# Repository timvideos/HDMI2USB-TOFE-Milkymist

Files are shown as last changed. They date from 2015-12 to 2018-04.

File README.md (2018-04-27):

## Milkymist Compatibility - TOFE Expansion board

The [Numato Opsis board](https://numato.com/product/numato-opsis-fpga-based-open-video-platform) is
already very similar to the [Milkymist M1](http://m-labs.hk/m1.html) and
[Mixxeo](http://m-labs.hk/mixxeo.html) devices created by
[M-Labs](http://m-labs.hk/), but lacks the DJ hardware interfaces. This
expansion board adds these missing components.

This board can be ordered from the
[Numato Opsis page on CrowdSupply.com](https://www.crowdsupply.com/numato-lab/opsis).

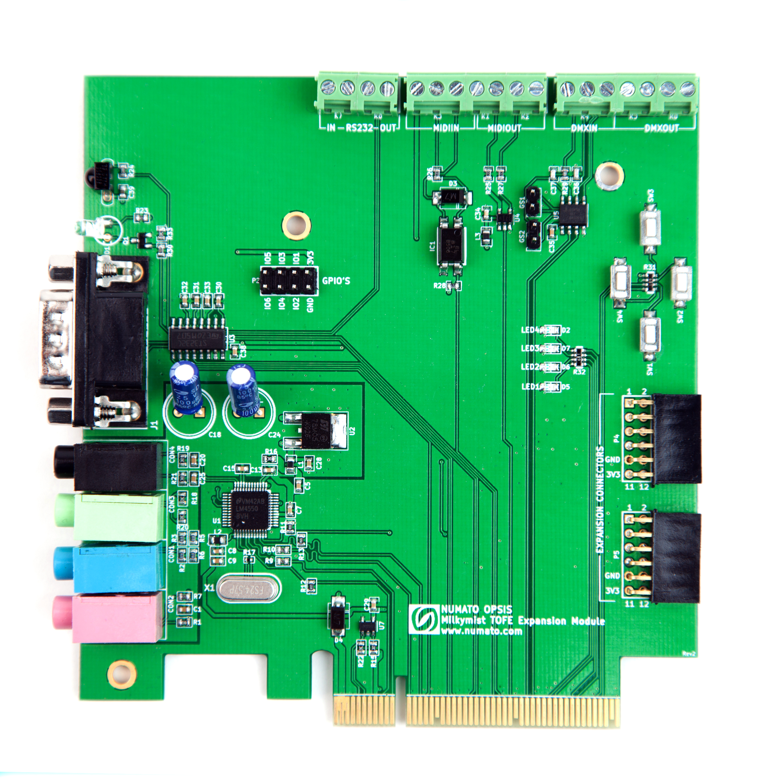
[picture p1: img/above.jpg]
Board Image


## Features

This extension board has the following features;

 * [AC‘97 compatible](https://en.wikipedia.org/wiki/AC%2797)
   audio interface with Microphone, Headphones, Line In + Out (on standard
   3.5mm connectors).

 * [RS-422](https://en.wikipedia.org/wiki/RS-422) / [RS-485](https://en.wikipedia.org/wiki/RS-485)
   compatible high speed (10Mbps), full duplex serial port;

    * Compatible with wide range of interfaces including the industry standard
      [DMX512 control protocol](https://en.wikipedia.org/wiki/DMX512).

    * Connected to screw terminal headers, allowing wiring to DB-9, RJ-12,
      XLR-5, XLR-3 or RJ-45 connectors (wiring diagrams provided).

 * [RS-232](https://en.wikipedia.org/wiki/RS-232) full duplex serial port on a
   standard DB-9 connector. Supporting connection to wide range of devices with
   serial ports. (A secondary RS-232 full duplex serial port on a standard
   screw terminal.)

 * [MIDI](https://en.wikipedia.org/wiki/MIDI) In and Out interfaces on screw
   terminals, supporting connection to wide range of musical instruments and
   control devices.

 * [Infrared](https://learn.adafruit.com/ir-sensor/ir-remote-signals)
   transmitter and receiver compatible with manys
   [consumer remote protocols](https://en.wikipedia.org/wiki/Consumer_IR).

 * 4 x Push button Switches,
 * 4 x Indicator LEDs,

 * 2 x [Digilent Pmod™ Compatible](http://www.digilentinc.com/Pmods/licensing.cfm)
   headers to allow usage of existing expansion boards, including boards froms
   [Numato Lab](http://numato.com/fpga-boards/filter/cat/expansion-modules.html?limit=30),
   [Digilent](http://digilentinc.com/pmods),
   [Maxim](https://www.maximintegrated.com/en/design/design-technology/fpga-design-resources/pmod-compatible-plug-in-peripheral-modules.html) ands
   [Analog](https://wiki.analog.com/resources/alliances/xilinx#pmods).

A PDF version of the schematic can be found in the [docs](docs) directory.

## Editing

The design in this repository was made using [KiCad](http://www.kicad-pcb.org/)
version **2013-07-07 BZR 4022**
([the version is Ubuntu Trusty](http://packages.ubuntu.com/trusty/kicad)).

## License

TOFE MilkyMist Compatibility Expansion board by Numato Systems Pvt. Ltd

TOFE MilkyMist Compatibility Expansion board is licensed under a
Creative Commons Attribution-ShareAlike 4.0 International License.

You should have received a copy of the license along with this
work. If not, see <http://creativecommons.org/licenses/by-sa/4.0/>.



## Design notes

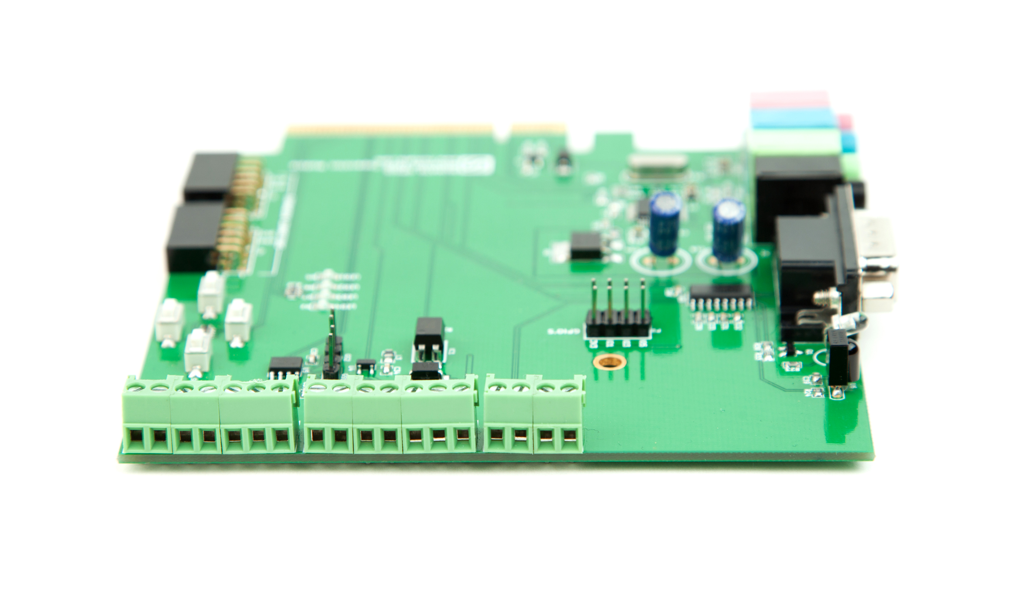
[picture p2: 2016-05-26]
img/top-edge.jpg

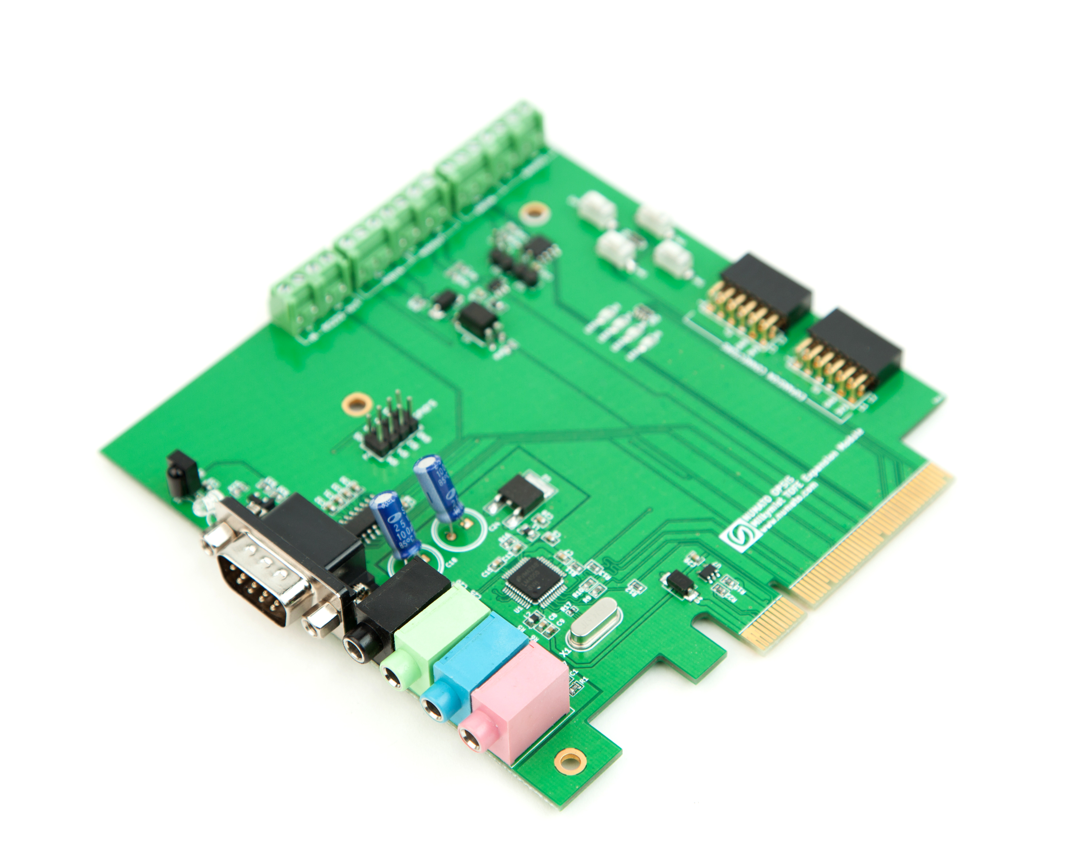
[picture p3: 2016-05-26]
img/45degree.jpg

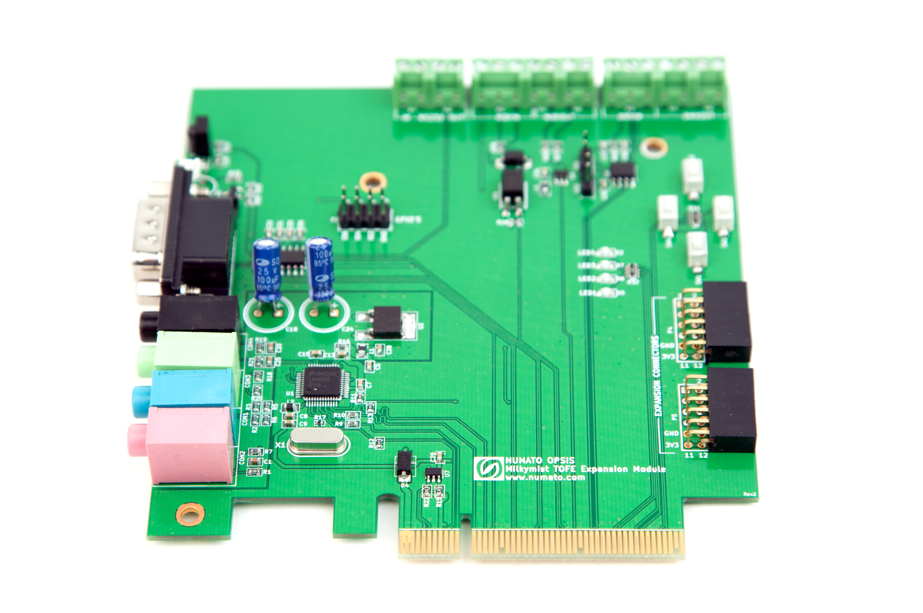
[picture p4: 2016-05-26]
img/angle.jpg

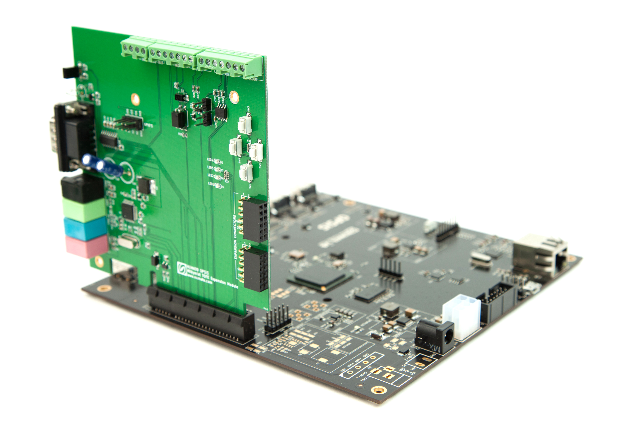
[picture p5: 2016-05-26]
img/action.jpg

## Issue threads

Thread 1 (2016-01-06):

Board is missing jumper for EEPROM write protection

mithro, 2016-01-06:
From the datasheet for the EEPROM;

```
2.4 Write-Protect (WP)
This pin must be connected to either VSS or VCC.
If tied to VSS, normal memory operation is enabled
(read/write the entire memory 00-7F).
If tied to VCC, write operations are inhibited. The entire
memory will be write-protected. Read operations are
not affected.
```

By default WP should be pulled to VCC so the EEPROM can't be overwritten. When programming WP should be pulled low.

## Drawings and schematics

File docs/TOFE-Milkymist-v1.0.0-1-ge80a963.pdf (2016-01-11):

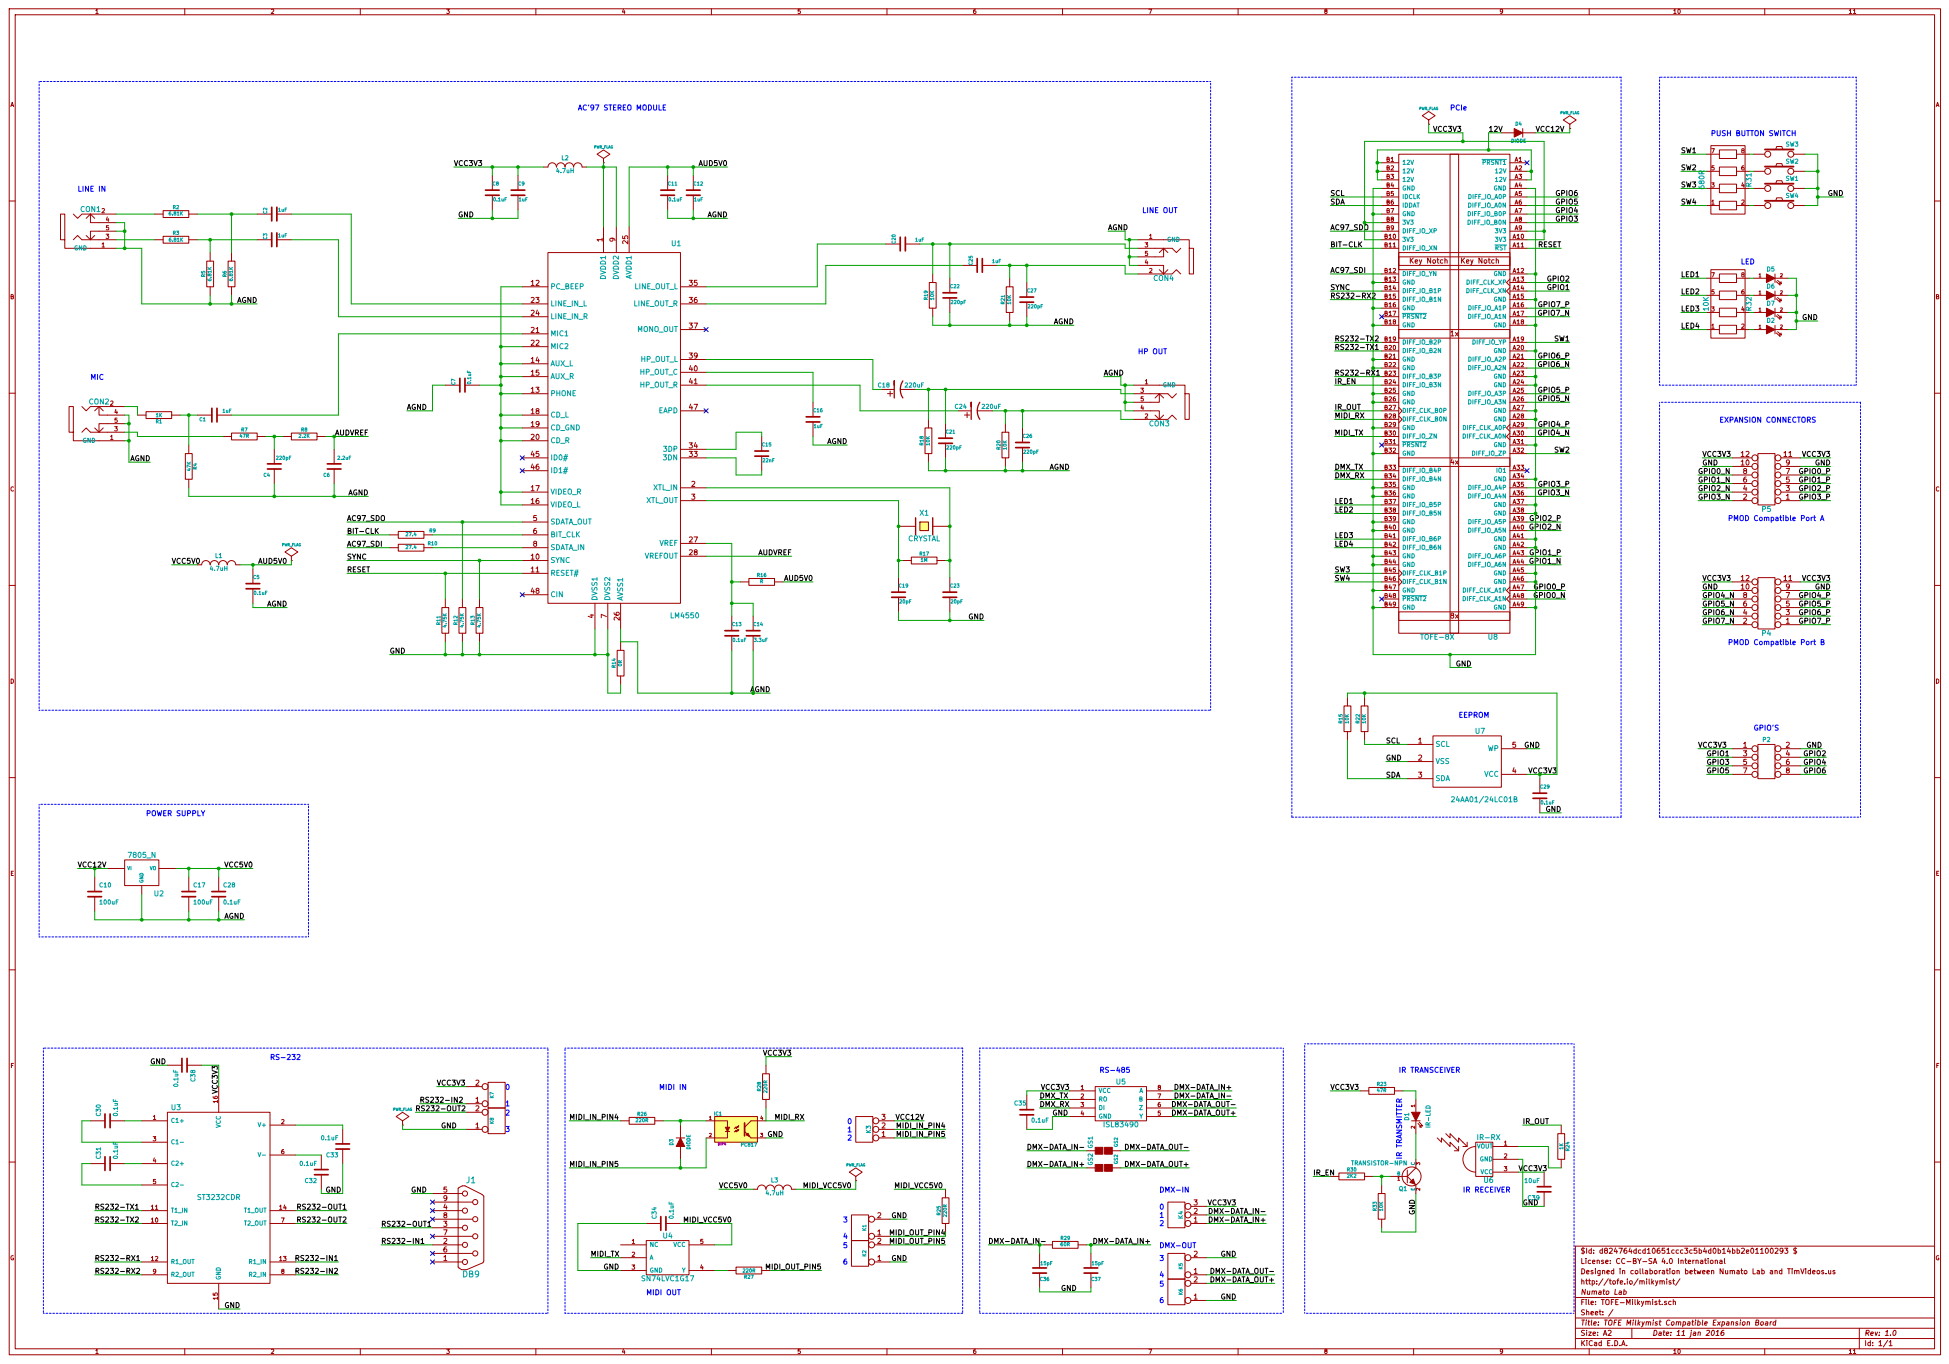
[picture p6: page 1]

MIDI IN MIDI OUT

License: CC-BY-SA 4.0 International
Designed in collaboration between Numato Lab and TimVideos.us
http://tofe.io/milkymist/
Sheet: / Numato Lab
File: TOFE-Milkymist.sch

Title: TOFE Milkymist Compatible Expansion Board
KiCad E.D.A.

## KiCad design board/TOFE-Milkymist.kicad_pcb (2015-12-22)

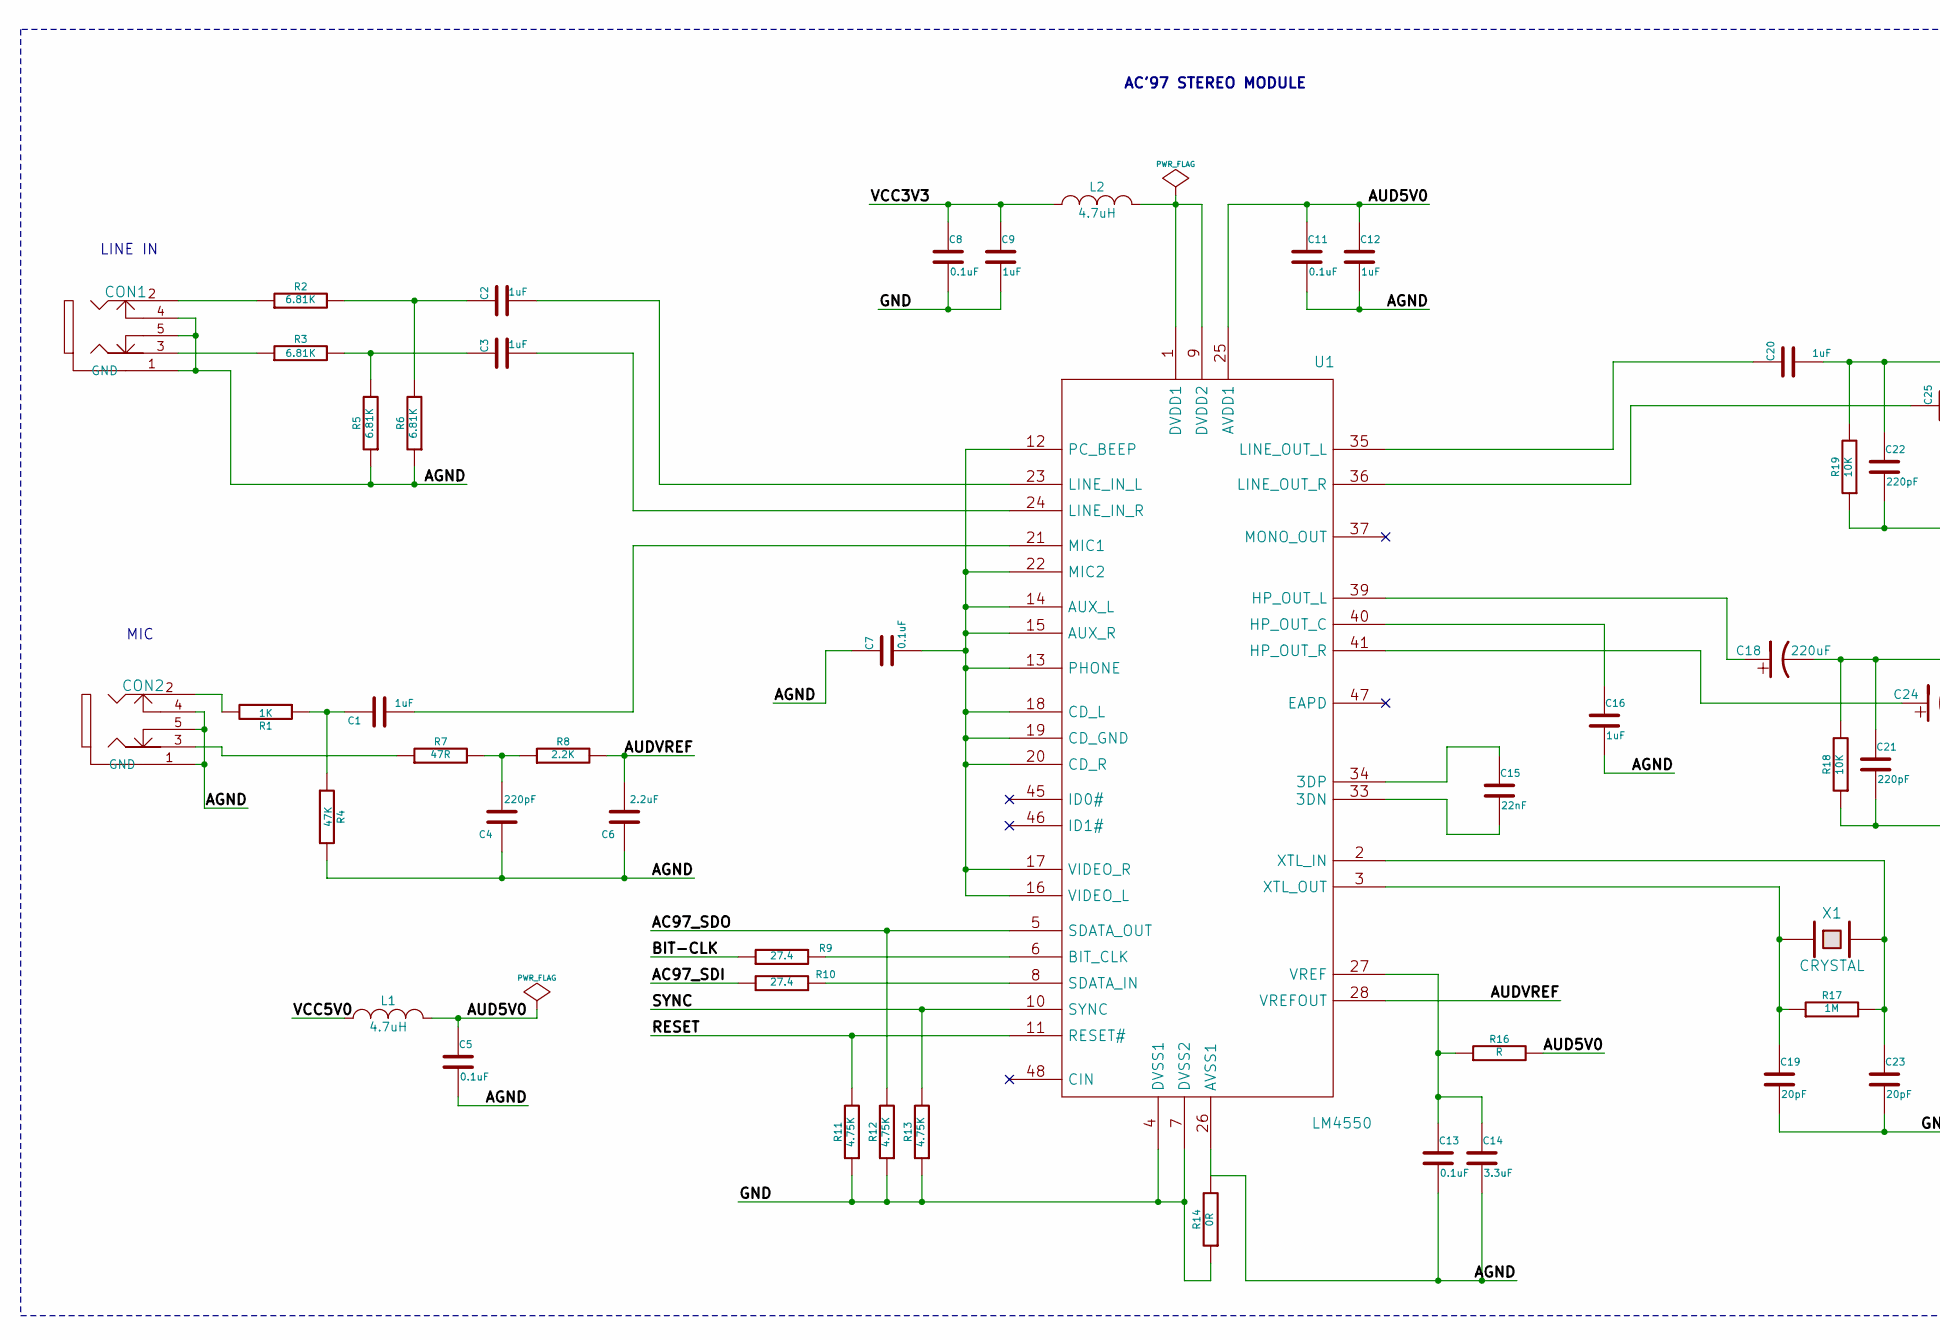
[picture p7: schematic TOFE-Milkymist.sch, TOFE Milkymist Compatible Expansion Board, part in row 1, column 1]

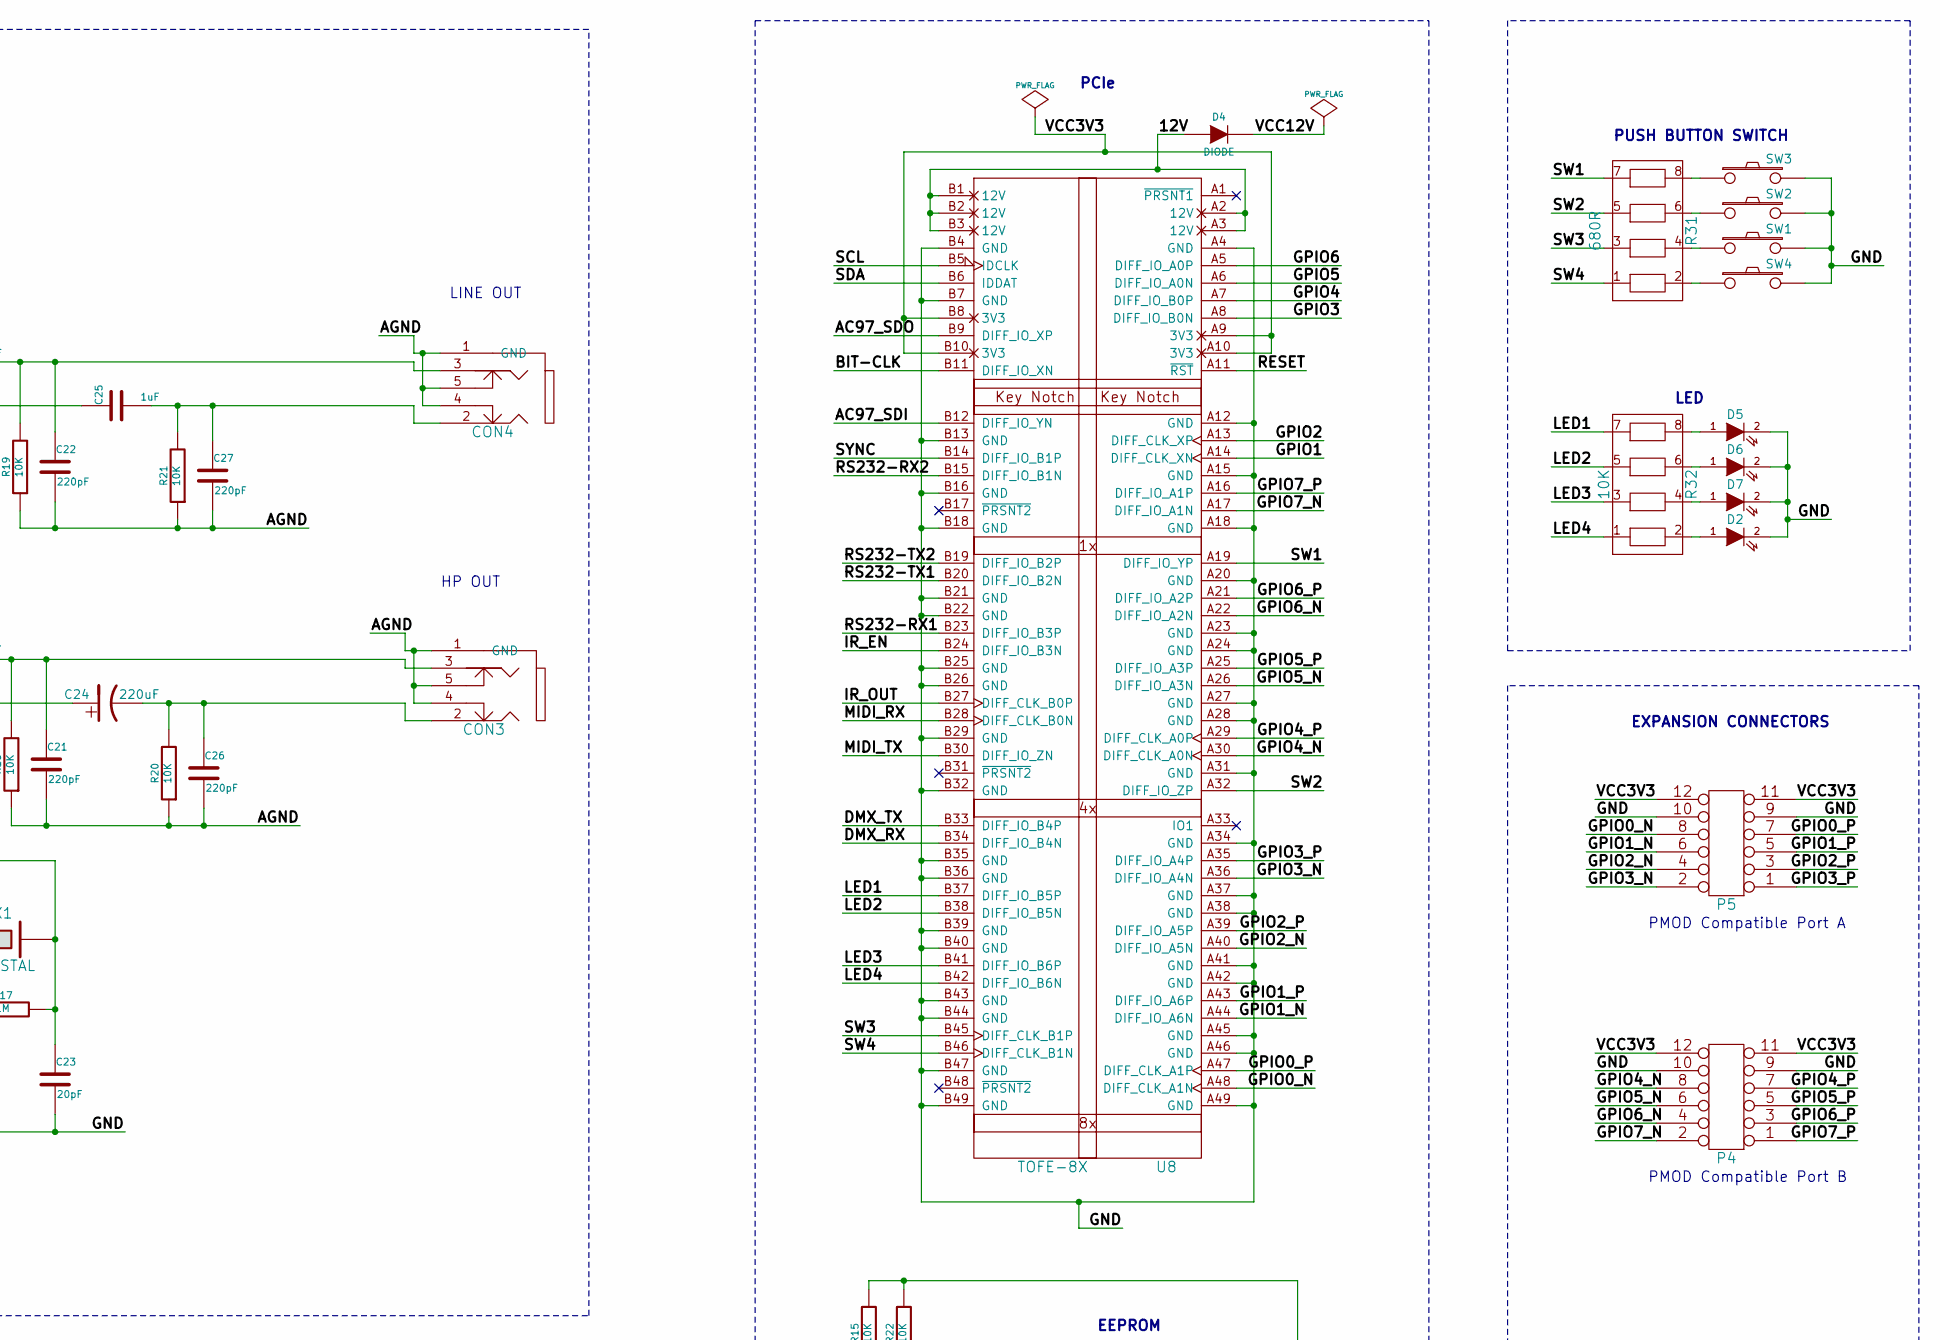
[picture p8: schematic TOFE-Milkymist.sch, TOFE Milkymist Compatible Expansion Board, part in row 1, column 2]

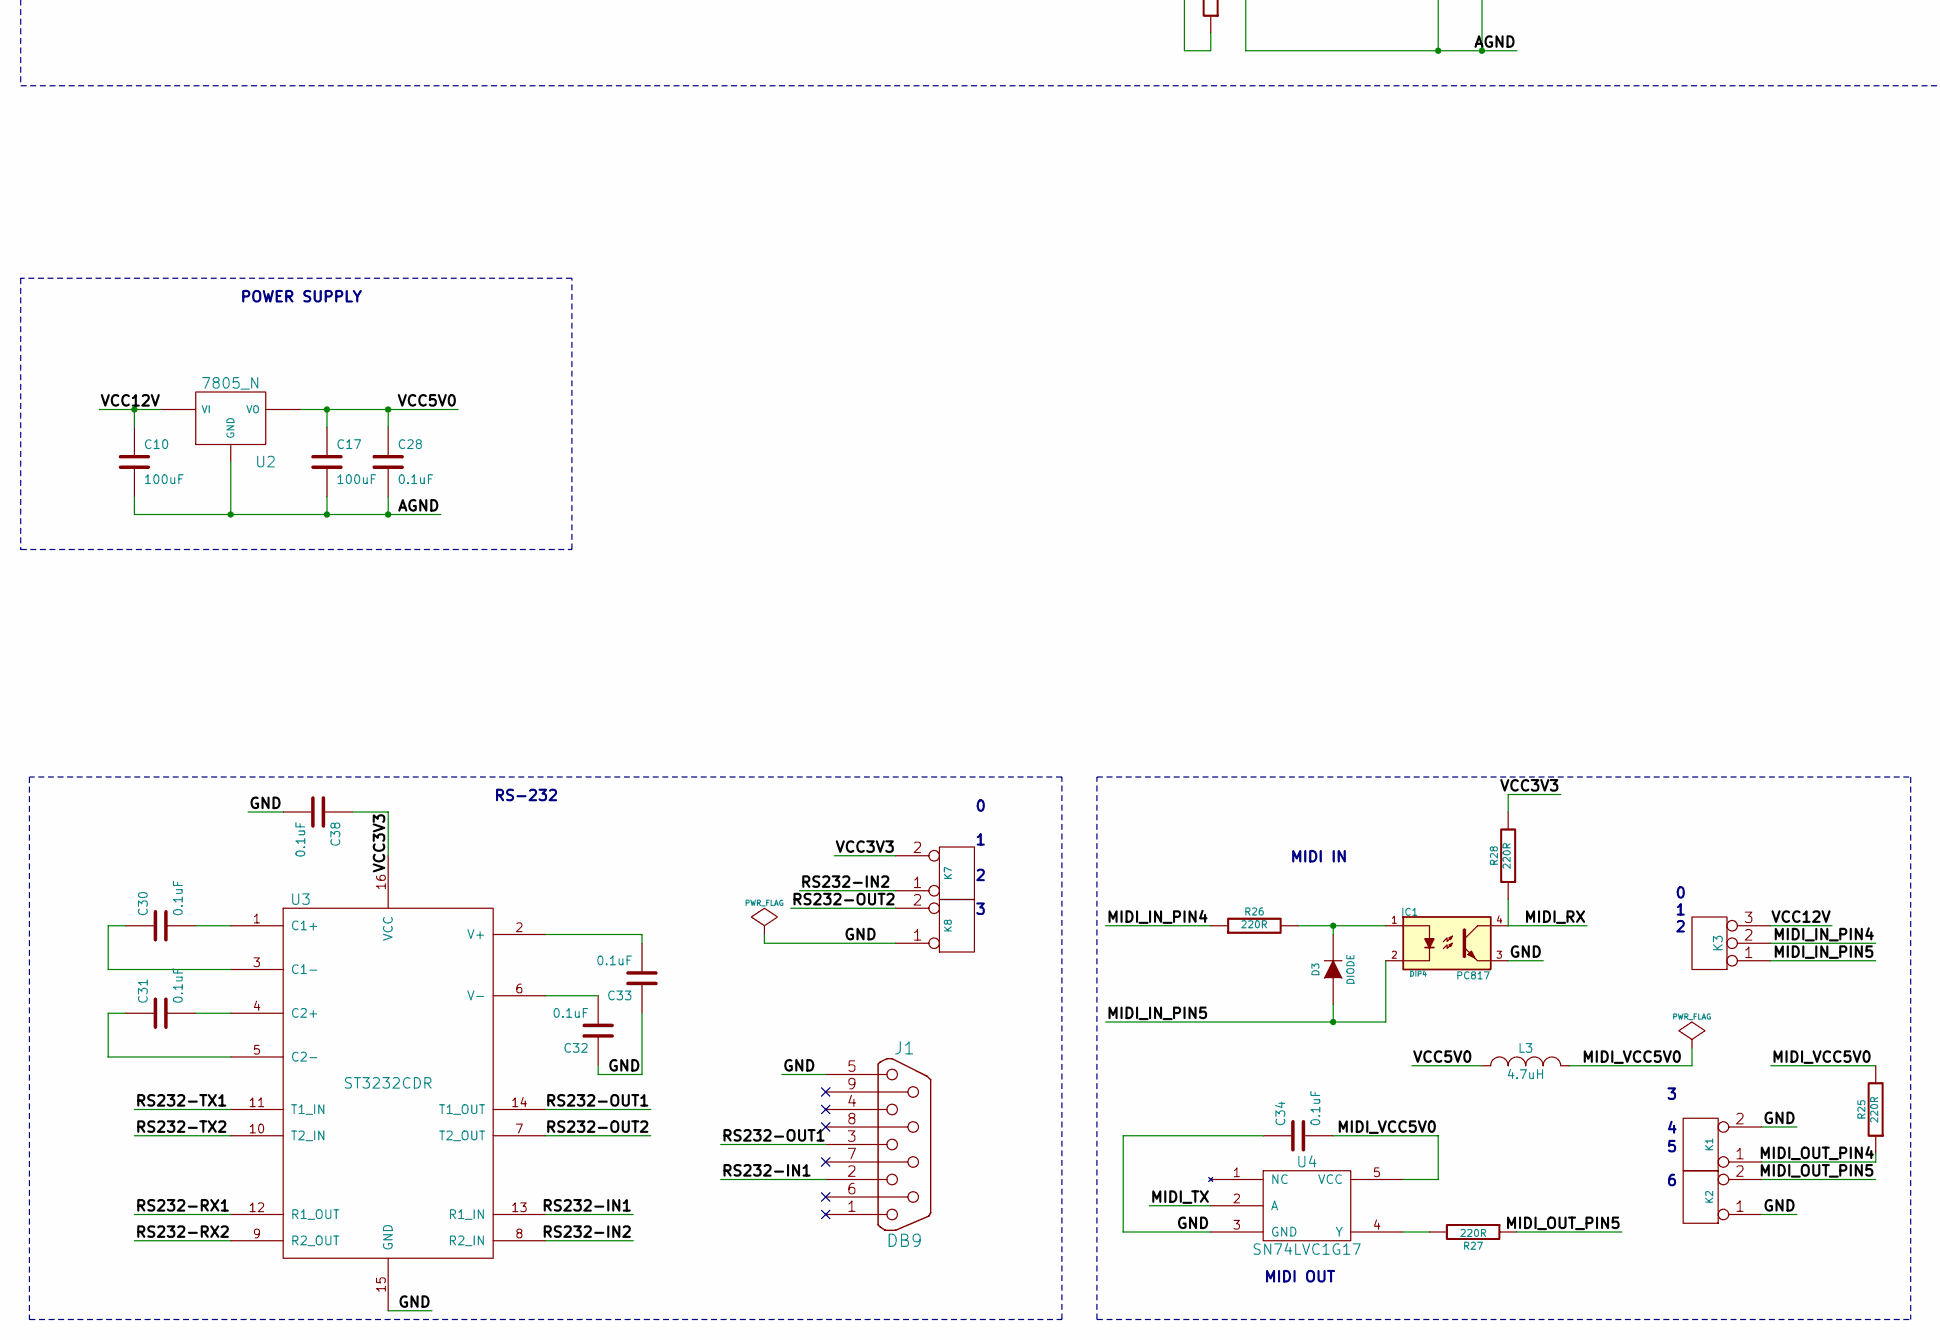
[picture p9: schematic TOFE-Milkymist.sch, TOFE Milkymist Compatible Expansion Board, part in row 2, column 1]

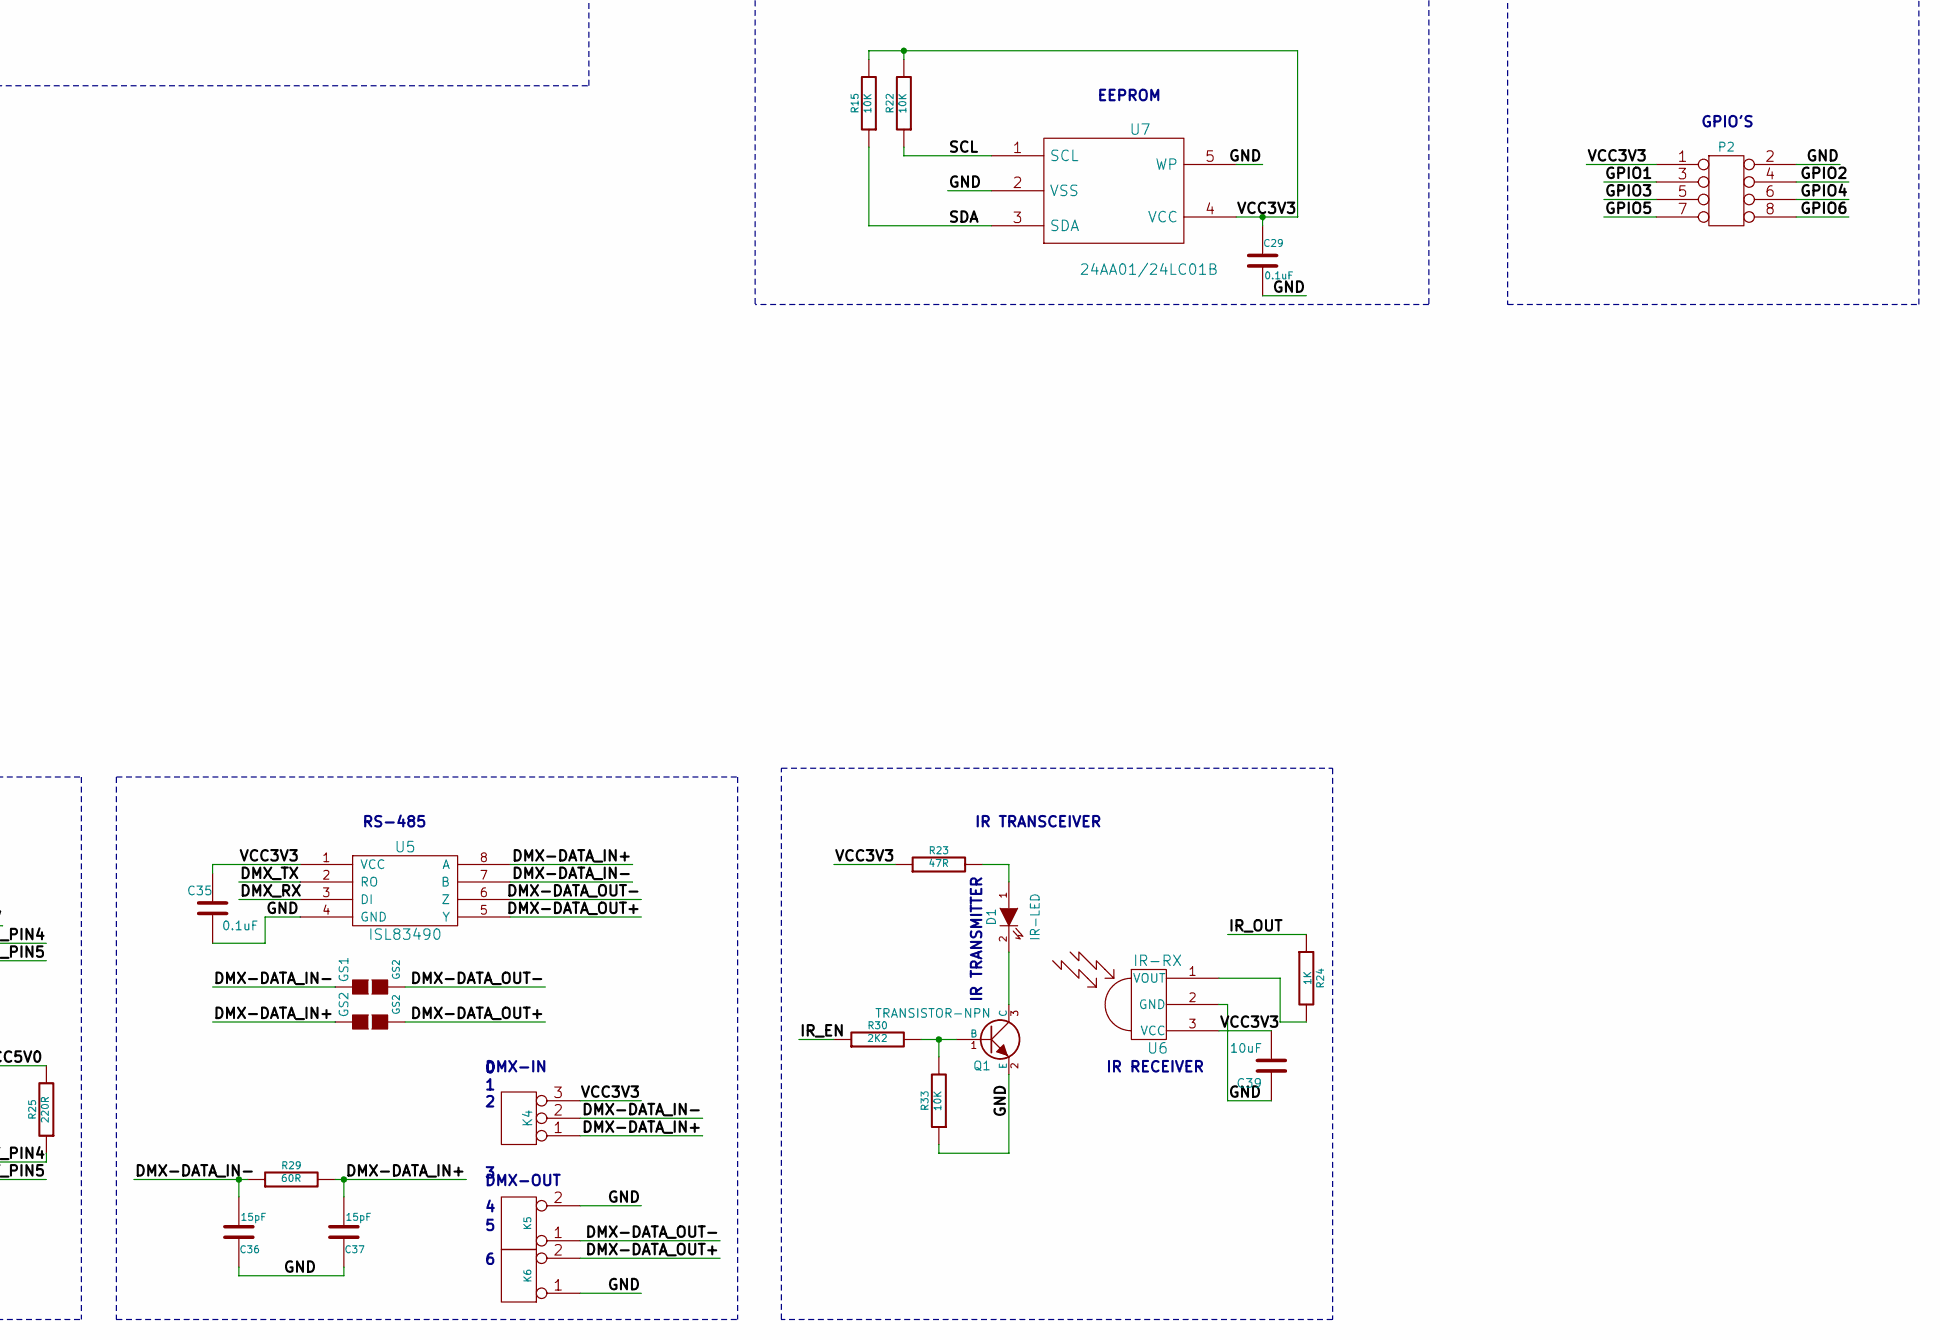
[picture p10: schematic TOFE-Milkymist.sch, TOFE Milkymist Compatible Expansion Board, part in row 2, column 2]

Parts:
C1, C2, C3, C9, C12, C16, C20, C25: 1uF
C4, C21, C22, C26, C27: 220pF
C5, C7, C8, C11, C13, C28, C29, C30, C31, C32, C33, C34, C35, C38: 0.1uF
C6: 2.2uF
C10, C17: 100uF
C14: 3.3uF
C15: 22nF
C18, C24: 220uF
C19, C23: 20pF
C36, C37: 15pF
C39: 10uF
CON1, CON2, CON3, CON4: AUDIO_JACK_3535NG
D1: IR-LED
D2, D5, D6, D7: LED
D3, D4: DIODE
GS1, GS2: GS2
IC1: PC817; DIP4
J1: DB9
K1, K2, K5, K6, K7, K8: CONN_2
K3, K4: CONN_3
L1, L2, L3: 4.7uH
P2: CONN_4X2
P4, P5: CONN_6X2
Q1: TRANSISTOR-NPN
R1, R24: 1K
R2, R3, R5, R6: 6.81K
R4: 47K
R7, R23: 47R
R8: 2.2K
R9, R10: 27.4
R11, R12, R13: 4.75K
R14: 0R
R15, R18, R19, R20, R21, R22, R32, R33: 10K
R16: R
R17: 1M
R25, R26, R27, R28: 220R
R29: 60R
R30: 2K2
R31: 680R
SW1, SW2, SW3, SW4: SW_PUSH
U1: LM4550
U2: 7805_N
U3: ST3232CDR
U4: SN74LVC1G17
U5: ISL83490
U6: IR-RX
U7: 24AA01/24LC01B
U8: TOFE-8X
X1: CRYSTAL

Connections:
/12V: D4.1 (A), U8.A2 (12V), U8.A3 (12V), U8.B1 (12V), U8.B2 (12V), U8.B3 (12V)
/AC97_SDI: R10.1, U8.B12 (DIFF_IO_YN)
/AC97_SDO: R12.2, U1.5 (SDATA_OUT), U8.B9 (DIFF_IO_XP)
/AGND: C4.1, C5.2, C6.1, C7.1, C10.2, C11.2, C12.2, C13.2, C14.2, C16.2, C17.2, C21.2, C22.2, C26.2, C27.2, C28.2, CON1.1 (GND), CON1.4, CON1.5, CON2.1 (GND), CON2.4, CON2.5, CON3.1 (GND), CON3.4, CON3.5, CON4.1 (GND), CON4.4, CON4.5, R4.2, R5.1, R6.1, R14.2, R18.1, R19.1, R20.1, R21.1, U1.26 (AVSS1), U2.2 (GND)
/AUD5V0: C5.1, C11.1, C12.1, L1.2, R16.2, U1.25 (AVDD1)
/AUDVREF: C6.2, R8.2, U1.28 (VREFOUT)
/BIT-CLK: R9.1, U8.B11 (DIFF_IO_XN)
/DMX-DATA_IN+: C37.2, GS2.1 (G1), K4.1, R29.2, U5.8 (A)
/DMX-DATA_IN-: C36.2, GS1.1 (G1), K4.2 (PM), R29.1, U5.7 (B)
/DMX-DATA_OUT+: GS2.2 (G2), K6.2 (PM), U5.5 (Y)
/DMX-DATA_OUT-: GS1.2 (G2), K5.1, U5.6 (Z)
/DMX_RX: U5.3 (DI), U8.B34 (DIFF_IO_B4N)
/DMX_TX: U5.2 (RO), U8.B33 (DIFF_IO_B4P)
/GND: C8.2, C9.2, C19.2, C23.2, C29.2, C32.1, C33.1, C34.1, C35.2, C36.1, C37.1, C38.2, C39.1, D2.2 (K), D5.2 (K), D6.2 (K), D7.2 (K), IC1.3, J1.5, K1.2 (PM), K2.1, K5.2 (PM), K6.1, K8.1, P2.2, P4.9, P4.10, P5.9, P5.10, Q1.2 (E), R11.1, R12.1, R13.1, R14.1, R33.1, SW1.2, SW2.2, SW3.2, SW4.2, U1.4 (DVSS1), U1.7 (DVSS2), U3.15 (GND), U4.3 (GND), U5.4 (GND), U6.2 (GND), U7.2 (VSS), U7.5 (WP), U8.A4 (GND), U8.A12 (GND), U8.A15 (GND), U8.A18 (GND), U8.A20 (GND), U8.A23 (GND), U8.A24 (GND), U8.A27 (GND), U8.A28 (GND), U8.A31 (GND), U8.A34 (GND), U8.A37 (GND), U8.A38 (GND), U8.A41 (GND), U8.A42 (GND), U8.A45 (GND), U8.A46 (GND), U8.A49 (GND), U8.B4 (GND), U8.B7 (GND), U8.B13 (GND), U8.B16 (GND), U8.B18 (GND), U8.B21 (GND), U8.B22 (GND), U8.B25 (GND), U8.B26 (GND), U8.B29 (GND), U8.B32 (GND), U8.B35 (GND), U8.B36 (GND), U8.B39 (GND), U8.B40 (GND), U8.B43 (GND), U8.B44 (GND), U8.B47 (GND), U8.B49 (GND)
/GPIO0_N: P5.8, U8.A48 (DIFF_CLK_A1N)
/GPIO0_P: P5.7, U8.A47 (DIFF_CLK_A1P)
/GPIO1: P2.3, U8.A14 (DIFF_CLK_XN)
/GPIO1_N: P5.6, U8.A44 (DIFF_IO_A6N)
/GPIO1_P: P5.5, U8.A43 (DIFF_IO_A6P)
/GPIO2: P2.4, U8.A13 (DIFF_CLK_XP)
/GPIO2_N: P5.4, U8.A40 (DIFF_IO_A5N)
/GPIO2_P: P5.3, U8.A39 (DIFF_IO_A5P)
/GPIO3: P2.5, U8.A8 (DIFF_IO_B0N)
/GPIO3_N: P5.2, U8.A36 (DIFF_IO_A4N)
/GPIO3_P: P5.1, U8.A35 (DIFF_IO_A4P)
/GPIO4: P2.6, U8.A7 (DIFF_IO_B0P)
/GPIO4_N: P4.8, U8.A30 (DIFF_CLK_A0N)
/GPIO4_P: P4.7, U8.A29 (DIFF_CLK_A0P)
/GPIO5: P2.7, U8.A6 (DIFF_IO_A0N)
/GPIO5_N: P4.6, U8.A26 (DIFF_IO_A3N)
/GPIO5_P: P4.5, U8.A25 (DIFF_IO_A3P)
/GPIO6: P2.8, U8.A5 (DIFF_IO_A0P)
/GPIO6_N: P4.4, U8.A22 (DIFF_IO_A2N)
/GPIO6_P: P4.3, U8.A21 (DIFF_IO_A2P)
/GPIO7_N: P4.2, U8.A17 (DIFF_IO_A1N)
/GPIO7_P: P4.1, U8.A16 (DIFF_IO_A1P)
/IR_EN: R30.1, U8.B24 (DIFF_IO_B3N)
/IR_OUT: R24.1, U8.B27 (DIFF_CLK_B0P)
/LED1: R32.7, U8.B37 (DIFF_IO_B5P)
/LED2: R32.5, U8.B38 (DIFF_IO_B5N)
/LED3: R32.3, U8.B41 (DIFF_IO_B6P)
/LED4: R32.1, U8.B42 (DIFF_IO_B6N)
/MIDI_IN_PIN4: K3.2 (PM), R26.1
/MIDI_IN_PIN5: D3.1 (A), IC1.2, K3.1
/MIDI_OUT_PIN4: K1.1, R25.1
/MIDI_OUT_PIN5: K2.2 (PM), R27.1
/MIDI_RX: IC1.4, R28.1, U8.B28 (DIFF_CLK_B0N)
/MIDI_TX: U4.2 (A), U8.B30 (DIFF_IO_ZN)
/MIDI_VCC5V0: C34.2, L3.2, R25.2, U4.5 (VCC)
/RESET: R11.2, U1.11 (RESET#), U8.A11 (~RST)
/RS232-IN1: J1.2, U3.13 (R1_IN)
/RS232-IN2: K7.1, U3.8 (R2_IN)
/RS232-OUT1: J1.3, U3.14 (T1_OUT)
/RS232-OUT2: K8.2 (PM), U3.7 (T2_OUT)
/RS232-RX1: U3.12 (R1_OUT), U8.B23 (DIFF_IO_B3P)
/RS232-RX2: U3.9 (R2_OUT), U8.B15 (DIFF_IO_B1N)
/RS232-TX1: U3.11 (T1_IN), U8.B20 (DIFF_IO_B2N)
/RS232-TX2: U3.10 (T2_IN), U8.B19 (DIFF_IO_B2P)
/SCL: R22.1, U7.1 (SCL), U8.B5 (IDCLK)
/SDA: R15.1, U7.3 (SDA), U8.B6 (IDDAT)
/SW1: R31.7, U8.A19 (DIFF_IO_YP)
/SW2: R31.5, U8.A32 (DIFF_IO_ZP)
/SW3: R31.3, U8.B45 (DIFF_CLK_B1P)
/SW4: R31.1, U8.B46 (DIFF_CLK_B1N)
/SYNC: R13.2, U1.10 (SYNC), U8.B14 (DIFF_IO_B1P)
/VCC3V3: C8.1, C9.1, C29.1, C35.1, C38.1, C39.2, K4.3, K7.2 (PM), L2.1, P2.1, P4.11, P4.12, P5.11, P5.12, R15.2, R22.2, R23.1, R28.2, U3.16 (VCC), U5.1 (VCC), U6.3 (VCC), U7.4 (VCC), U8.A9 (3V3), U8.A10 (3V3), U8.B8 (3V3), U8.B10 (3V3)
/VCC5V0: C17.1, C28.1, L1.1, L3.1, U2.3 (VO)
/VCC12V: C10.1, D4.2 (K), K3.3, U2.1 (VI)
unnamed: CON2.3, R7.1
unnamed: CON2.2, R1.2
unnamed: C3.2, U1.24 (LINE_IN_R)
unnamed: C2.2, U1.23 (LINE_IN_L)
unnamed: C13.1, C14.1, R16.1, U1.27 (VREF)
unnamed: C18.2, C21.1, CON3.3, R18.2
unnamed: C24.1, U1.41 (HP_OUT_R)
unnamed: C15.2, U1.33 (3DN)
unnamed: C15.1, U1.34 (3DP)
unnamed: R10.2, U1.8 (SDATA_IN)
unnamed: R9.2, U1.6 (BIT_CLK)
unnamed: C1.1, R1.1, R4.1
unnamed: C20.1, U1.35 (LINE_OUT_L)
unnamed: C25.1, U1.36 (LINE_OUT_R)
unnamed: C1.2, U1.21 (MIC1)
unnamed: C4.2, R7.2, R8.1
unnamed: C16.1, U1.40 (HP_OUT_C)
unnamed: C24.2, C26.1, CON3.2, R20.2
unnamed: C25.2, C27.1, CON4.2, R21.2
unnamed: C20.2, C22.1, CON4.3, R19.2
unnamed: C18.1, U1.39 (HP_OUT_L)
unnamed: R27.2, U4.4 (Y)
unnamed: R31.2, SW4.1
unnamed: R24.2, U6.1 (VOUT)
unnamed: D1.2 (K), Q1.3 (C)
unnamed: Q1.1 (B), R30.2, R33.2
unnamed: D1.1 (A), R23.2
unnamed: D7.1 (A), R32.4
unnamed: D6.1 (A), R32.6
unnamed: D5.1 (A), R32.8
unnamed: R31.4, SW1.1
unnamed: R31.6, SW2.1
unnamed: R31.8, SW3.1
unnamed: C30.2, U3.1 (C1+)
unnamed: C33.2, U3.2 (V+)
unnamed: C31.1, U3.5 (C2-)
unnamed: C31.2, U3.4 (C2+)
unnamed: C30.1, U3.3 (C1-)
unnamed: D2.1 (A), R32.2
unnamed: C32.2, U3.6 (V-)
unnamed: D3.2 (K), IC1.1, R26.2
unnamed: CON1.3, R3.1
unnamed: CON1.2, R2.1
unnamed: C2.1, R2.2, R6.2
unnamed: C7.2, U1.12 (PC_BEEP), U1.13 (PHONE), U1.14 (AUX_L), U1.15 (AUX_R), U1.16 (VIDEO_L), U1.17 (VIDEO_R), U1.18 (CD_L), U1.19 (CD_GND), U1.20 (CD_R), U1.22 (MIC2)
unnamed: C23.1, R17.2, U1.2 (XTL_IN), X1.2
unnamed: C19.1, R17.1, U1.3 (XTL_OUT), X1.1
unnamed: L2.2, U1.1 (DVDD1), U1.9 (DVDD2)
unnamed: C3.1, R3.2, R5.2

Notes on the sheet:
LINE IN
LINE OUT
HP OUT
MIC
PUSH BUTTON SWITCH
LED
PCIe
EEPROM
MIDI IN
MIDI OUT
EXPANSION CONNECTORS
RS-485
POWER SUPPLY
AC'97 STEREO MODULE
RS-232
IR TRANSCEIVER
0 1 2
3 4
GPIO'S
DMX-IN
DMX-OUT
IR TRANSMITTER
IR RECEIVER
0 1
2 3
5 6
PMOD Compatible Port A
PMOD Compatible Port B

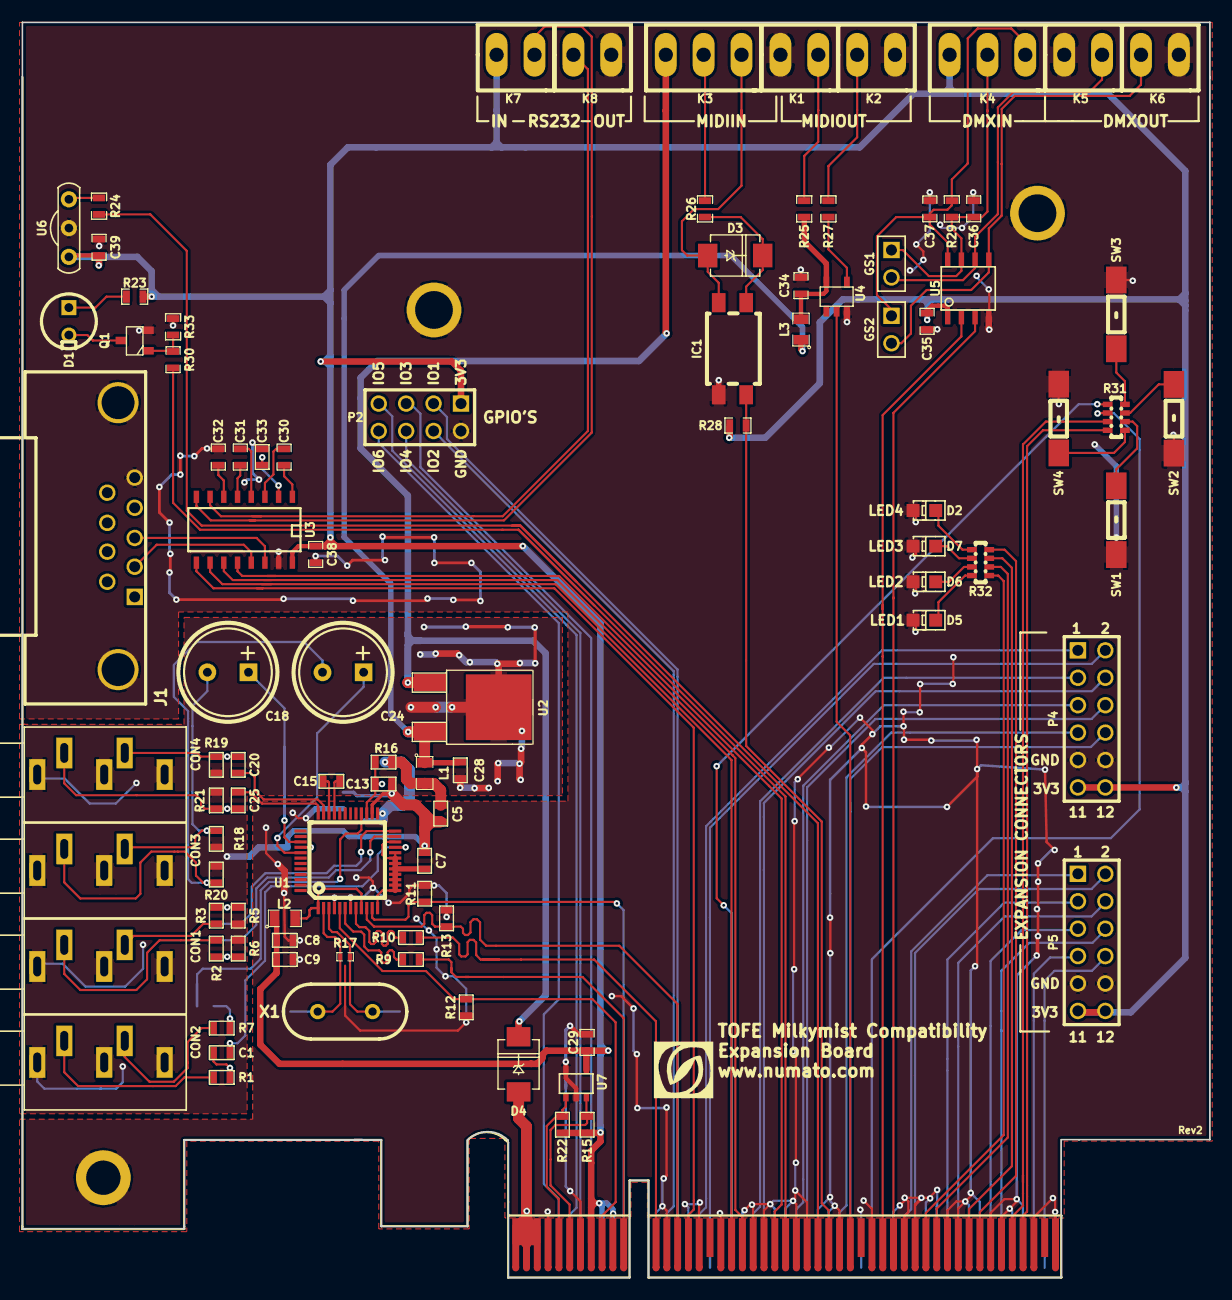
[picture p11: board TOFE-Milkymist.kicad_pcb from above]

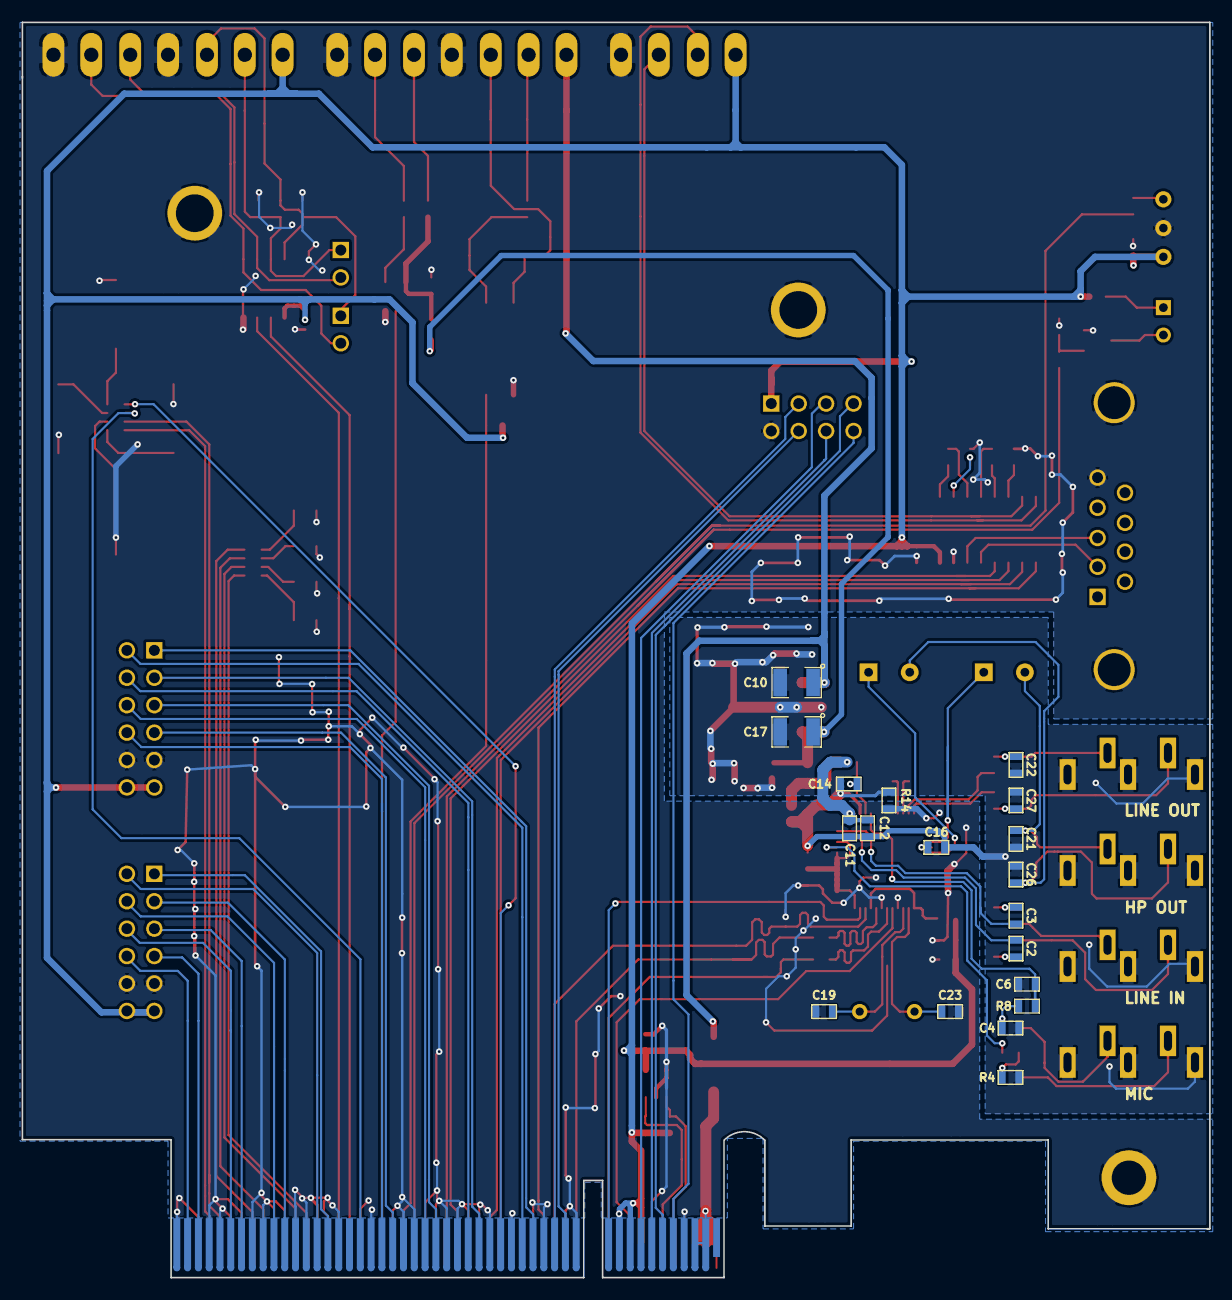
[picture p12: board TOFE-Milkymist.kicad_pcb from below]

Board: 2 copper layers, 110.0 x 116.3 mm, 115 parts (19 on the bottom side), 117 nets.

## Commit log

2015-11-03 Changes on 03-11-15
    [MilkymistCompatibleTOFEExpansionModule.kicad_pcb, MilkymistCompatibleTOFEExpansionModule.sch]
2015-11-03 changes on Mounting holes arrangement
    [MilkymistCompatibleTOFEExpansionModule.kicad_pcb]
2015-12-02 Mechanical hole changes
    [MilkymistCompatibleTOFEExpansionModule.kicad_pcb, MilkymistCompatibleTOFEExpansionModule.sch]
2015-12-22 Creating TOFE-Milkymist!
    [TOFE-Expansion-Board-Full-Height.kicad_pcb, TOFE-Milkymist.kicad_pcb, TOFE-Milkymist.sch]
2015-12-22 Initial version from on 2015-11-03
    [TOFE-Milkymist.kicad_pcb, TOFE-Milkymist.sch]
2015-12-22 Changing mounting holes arrangement.
    [TOFE-Milkymist.kicad_pcb]
2015-12-22 More changes to mechanical holes.
    [TOFE-Milkymist.kicad_pcb, TOFE-Milkymist.sch]
2015-12-22 Fixing part reference.
    [TOFE-Milkymist.kicad_pcb, TOFE-Milkymist.sch]
2015-12-22 Fixing switch alignment and adding extra comments.
    [TOFE-Milkymist.sch]
2015-12-22 Updated version sent to production.
    [TOFE-Milkymist.kicad_pcb, TOFE-Milkymist.sch]
2015-12-22 Gerber's sent to production.
    [TOFE-Milkymist-B_Cu.gbl, TOFE-Milkymist-B_Mask.gbs, TOFE-Milkymist-B_SilkS.gbo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]
2016-01-11 Improving comments.
    [TOFE-Milkymist.sch]
2016-01-11 Adding PDF of schematic.
2016-05-26 Adding images of the board.
2018-04-27 Link to current Opsis supplier page
